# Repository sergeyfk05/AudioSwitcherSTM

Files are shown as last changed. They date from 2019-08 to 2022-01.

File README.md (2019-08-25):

# Description
This project receives 4 or more audio channels to the input and outputs the first active audio channel in order of priority. 
If there is at least one active channel, then the logic unit is supplied to the LED and AMP outputs, thereby including a relay 
for the sound amplifier and an LED. The number of channels, sensitivity settings, pins can be configured in the settings. 
There are also other settings in the maine. All settings are well documented. There are tinctures that allow you to take 
measurements with different frequencies, individual for each channel, and much more.</br></br>

# Harware requirements
Code is written for STM32F103C8T6. Also you can use chinees' analogue.</br></br>

# Circuit and circuit board
You can find circuit, circuit board and gerber-files(needed for to order circuit board) in /Eagle/ directory. You can order the circuit board in <a href="https://JLCPCB.com">JLCPCB.com</a>.
It is very cheap, only $ 2 for 5 pcs.

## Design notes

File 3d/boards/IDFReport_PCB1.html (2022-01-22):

Altium customize

# IDF File Translation Report

Date: | | 01.01.2022
Time: | | 19:11:18
Elapsed Time: | | 00:00:00
PCB Filename | : | D:\Projects\AudioSwitcherSTM\Altium\BLE_Holder\PCB1.PcbDoc
IDF Board Filename | : | D:\Projects\AudioSwitcherSTM\3d\boards\PCB1.brd
IDF Library Filename | : | D:\Projects\AudioSwitcherSTM\3d\boards\PCB1.pro

Errors

Back to top

Warnings

Back to top

Save Warnings

Back to top

Save Errors

Back to top

Export Warnings

Back to top

Export Errors

Back to top

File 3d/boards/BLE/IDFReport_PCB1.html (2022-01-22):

Altium customize

# IDF File Translation Report

Date: | | 01.01.2022
Time: | | 19:09:44
Elapsed Time: | | 00:00:00
PCB Filename | : | D:\Projects\AudioSwitcherSTM\Altium\BLE_Holder\PCB1.PcbDoc
IDF Board Filename | : | D:\Projects\AudioSwitcherSTM\3d\boards\BLE\PCB1.brd
IDF Library Filename | : | D:\Projects\AudioSwitcherSTM\3d\boards\BLE\PCB1.pro

Errors

Back to top

Warnings

Back to top

Save Warnings

Back to top

Save Errors

Back to top

Export Warnings

Back to top

Export Errors

Back to top

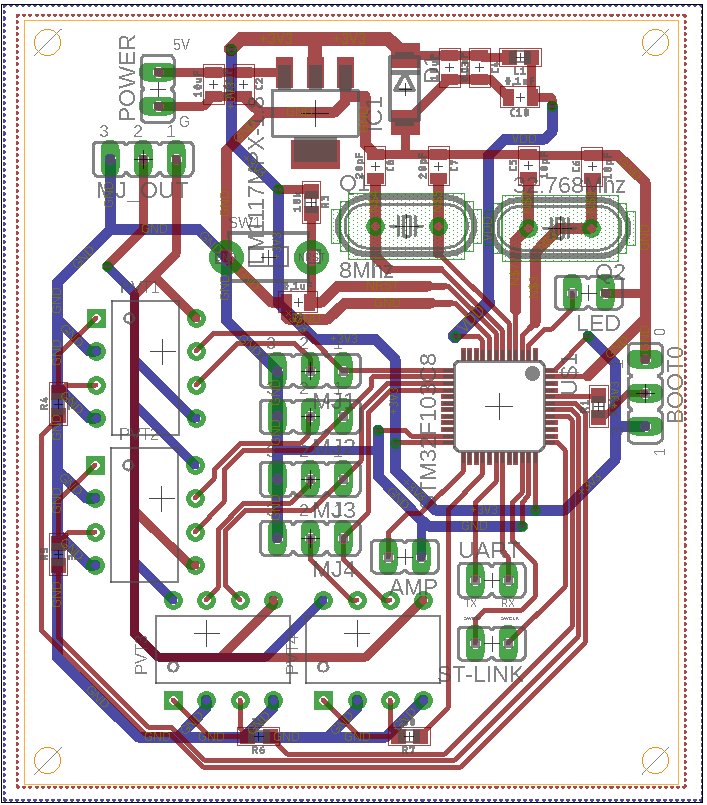
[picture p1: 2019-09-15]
scheme.png

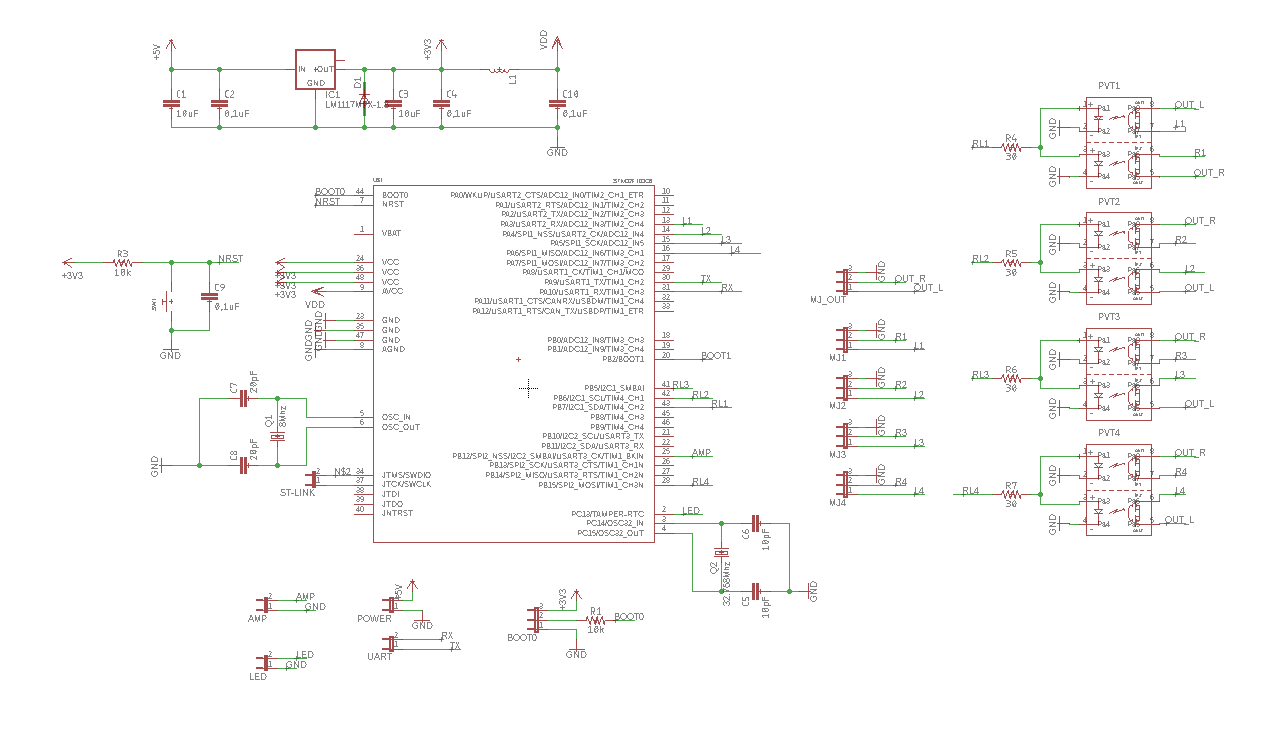
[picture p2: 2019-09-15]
circuit board.png

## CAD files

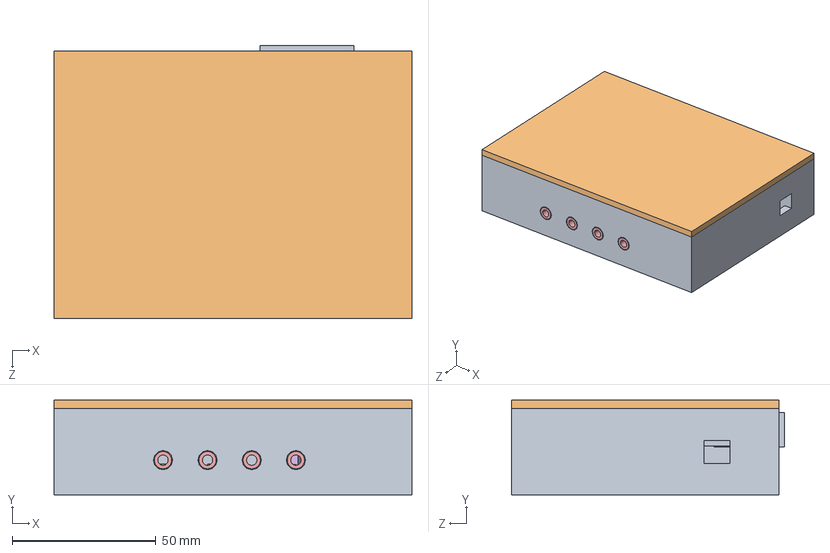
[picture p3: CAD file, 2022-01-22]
3d/case/assembly.SLDASM
124.5 x 33.0 x 95.1 mm
base_of_case
G5Q.step
Extruded.step x 10
Extruded-0.step x 5
Extruded-1.step x 30
Extruded-2.step x 15
Extruded-3.step x 8
Extruded-4.step x 16
Extruded-5.step x 5
Extruded-6.step x 10
Extruded-7.step x 2
PJ-307C.step x 5
`1.step
1.step
STM_Logo.step
TAS5-12-WEDT1.step
Extruded-8.step
Extruded-9.step
Extruded-10.step
Extruded-11.step
PCHSN-15 x 3
PCB1
771wx201
out_220v
top_of_case

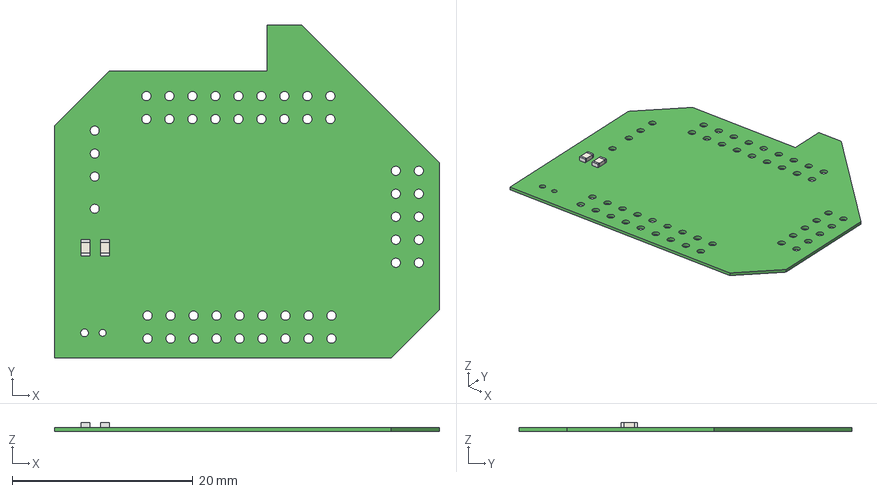
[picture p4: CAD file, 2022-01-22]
3d/boards/BLE/PCB1.step
42.5 x 36.8 x 0.961 mm
Extruded x 6

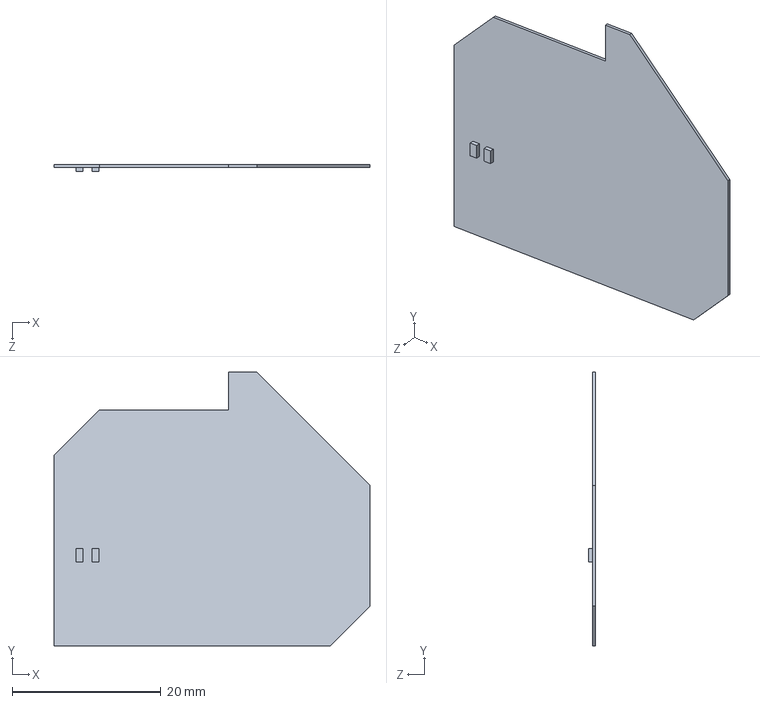
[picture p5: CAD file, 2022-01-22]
3d/boards/PCB1.SLDPRT
42.5 x 36.8 x 0.941 mm

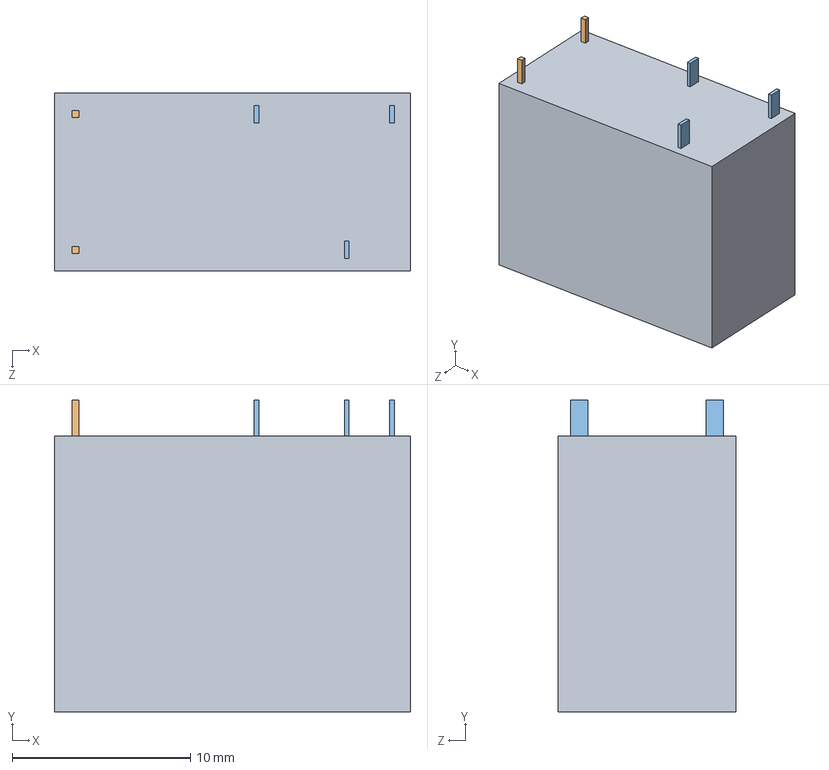
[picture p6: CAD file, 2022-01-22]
3d/components/G5Q.STEP
20.0 x 17.5 x 10.0 mm

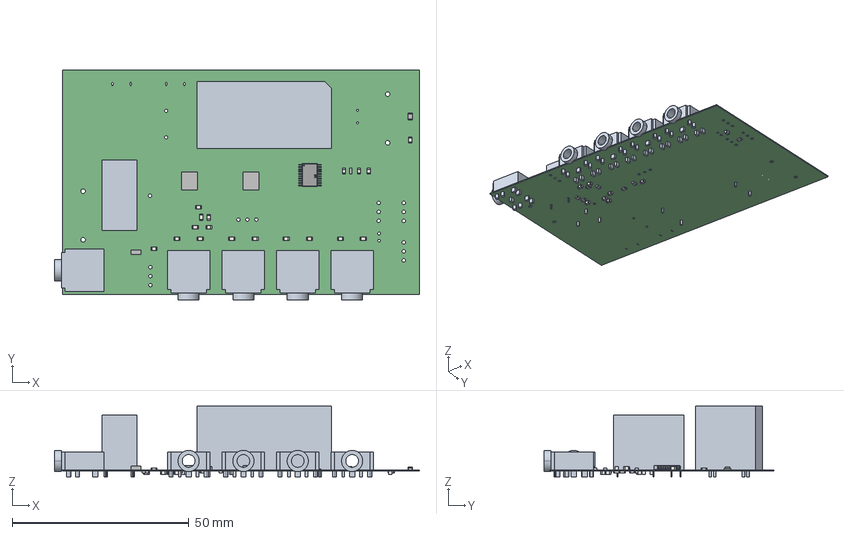
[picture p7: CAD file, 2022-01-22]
3d/boards/PCB.step
103.2 x 65.1 x 20.0 mm
G5Q
Extruded x 105
PJ-307C x 5
`1
STM_Logo
TAS5-12-WEDT1

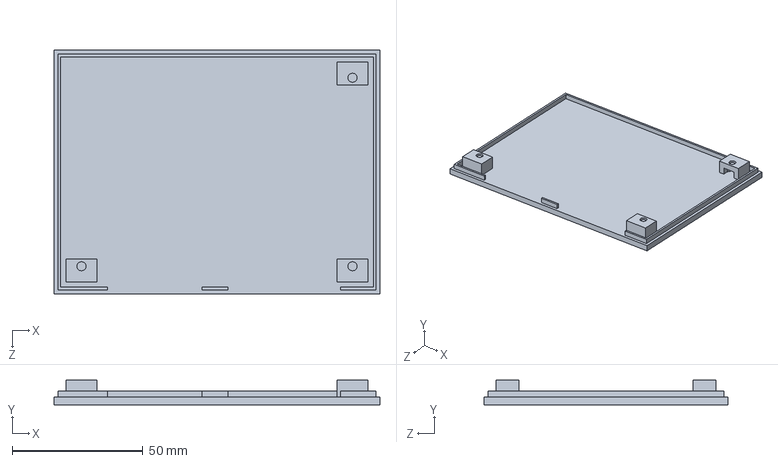
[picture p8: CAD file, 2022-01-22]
3d/case/top_of_case.SLDPRT
124.5 x 9.50 x 93.0 mm

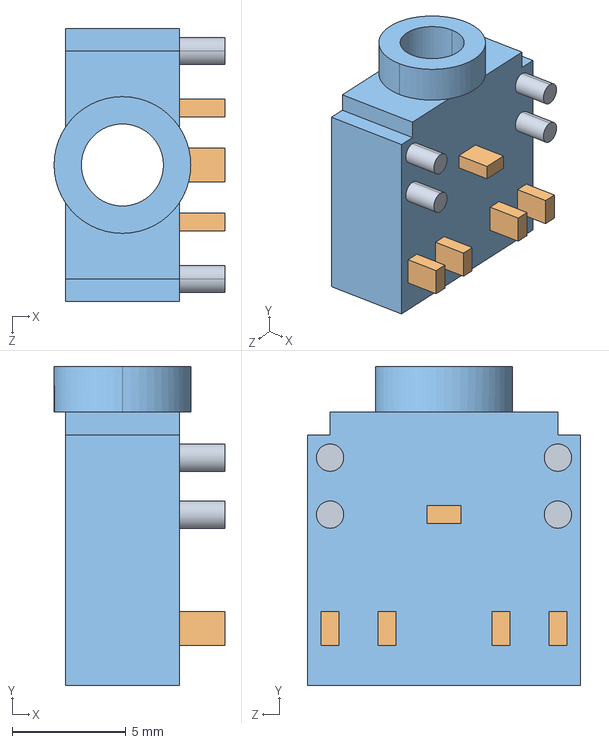
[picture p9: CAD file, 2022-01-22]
3d/components/PJ-307C.STEP
7.50 x 14.0 x 12.0 mm

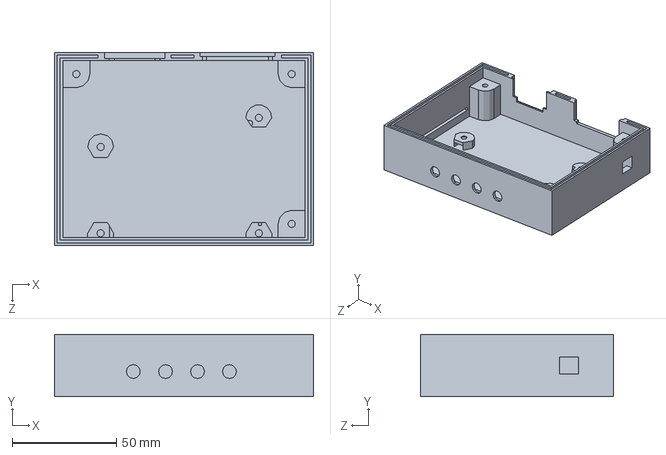
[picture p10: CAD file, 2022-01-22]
3d/case/base_of_case.SLDPRT
124.5 x 30.0 x 93.0 mm

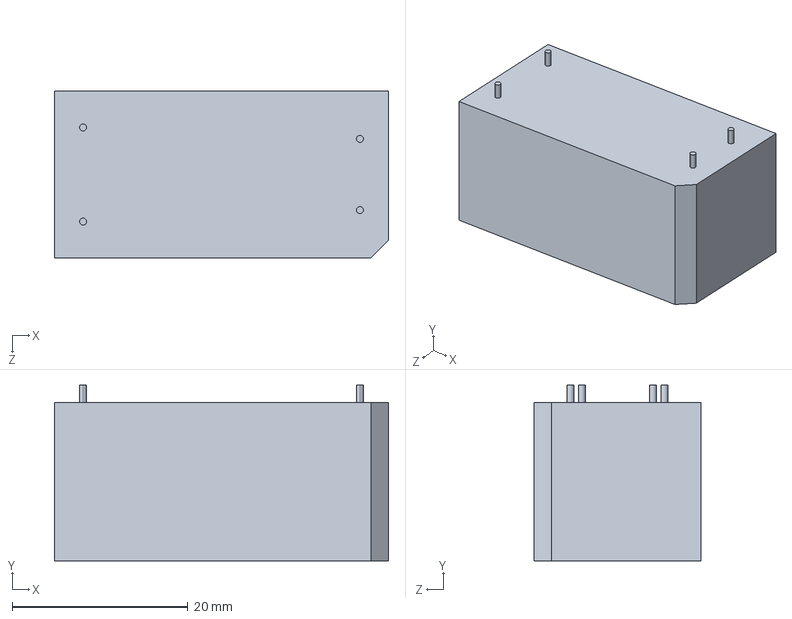
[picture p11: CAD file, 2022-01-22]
3d/components/TAS5-12-WEDT.STEP
38.0 x 20.0 x 19.0 mm

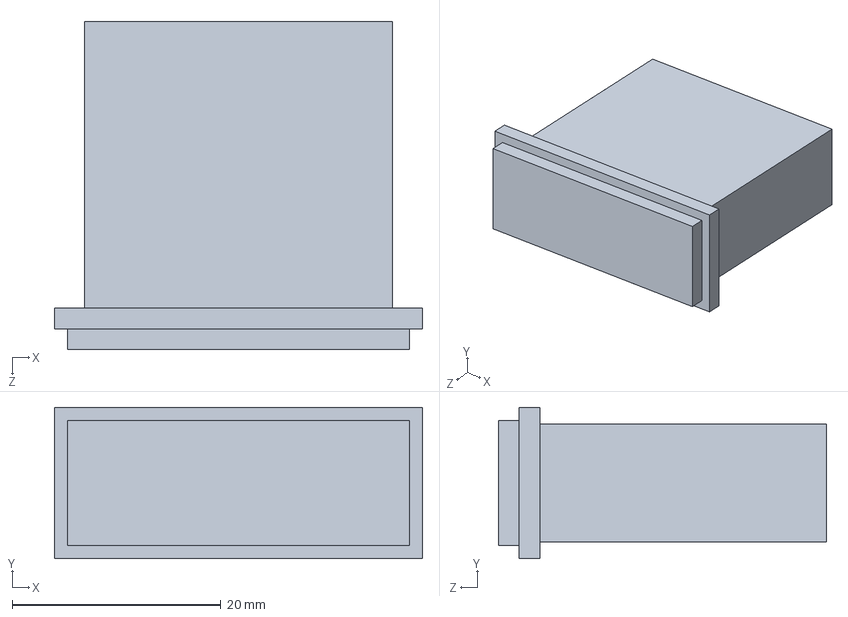
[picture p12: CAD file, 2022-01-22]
3d/case/out_220v.SLDPRT
35.3 x 14.5 x 31.5 mm

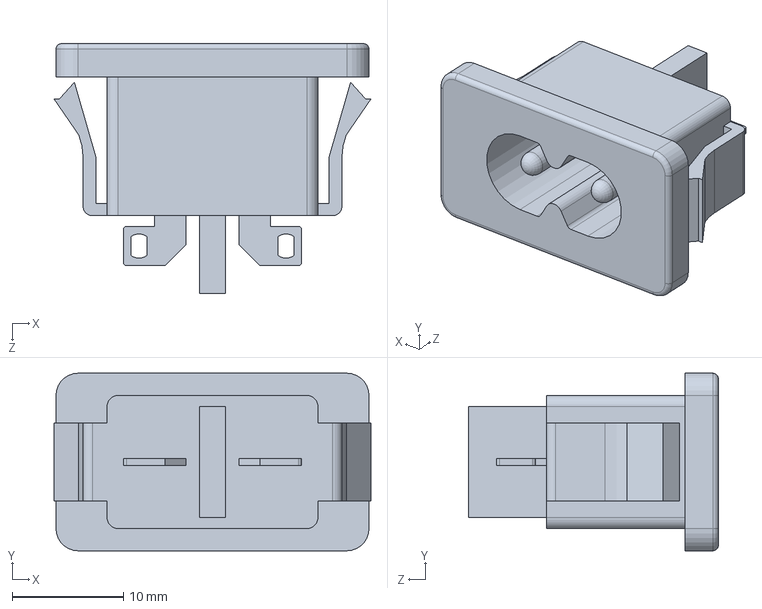
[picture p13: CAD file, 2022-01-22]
3d/case/771wx201.SLDPRT
28.6 x 16.0 x 22.5 mm

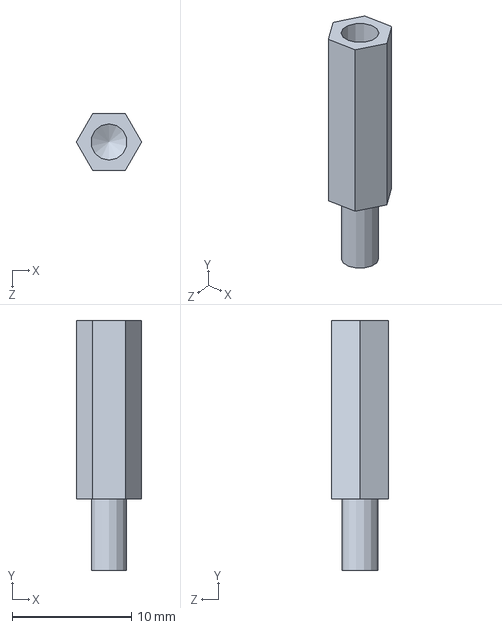
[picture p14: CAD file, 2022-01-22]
3d/case/PCHSN-15.SLDPRT
5.50 x 21.0 x 4.76 mm

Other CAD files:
3d/components/TAS5-12-WEDT1.STEP
3d/boards/BLE/PCB1.x_t
3d/components/G5Q.SLDPRT
3d/components/PJ-307C.SLDPRT
3d/components/TAS5-12-WEDT.SLDPRT

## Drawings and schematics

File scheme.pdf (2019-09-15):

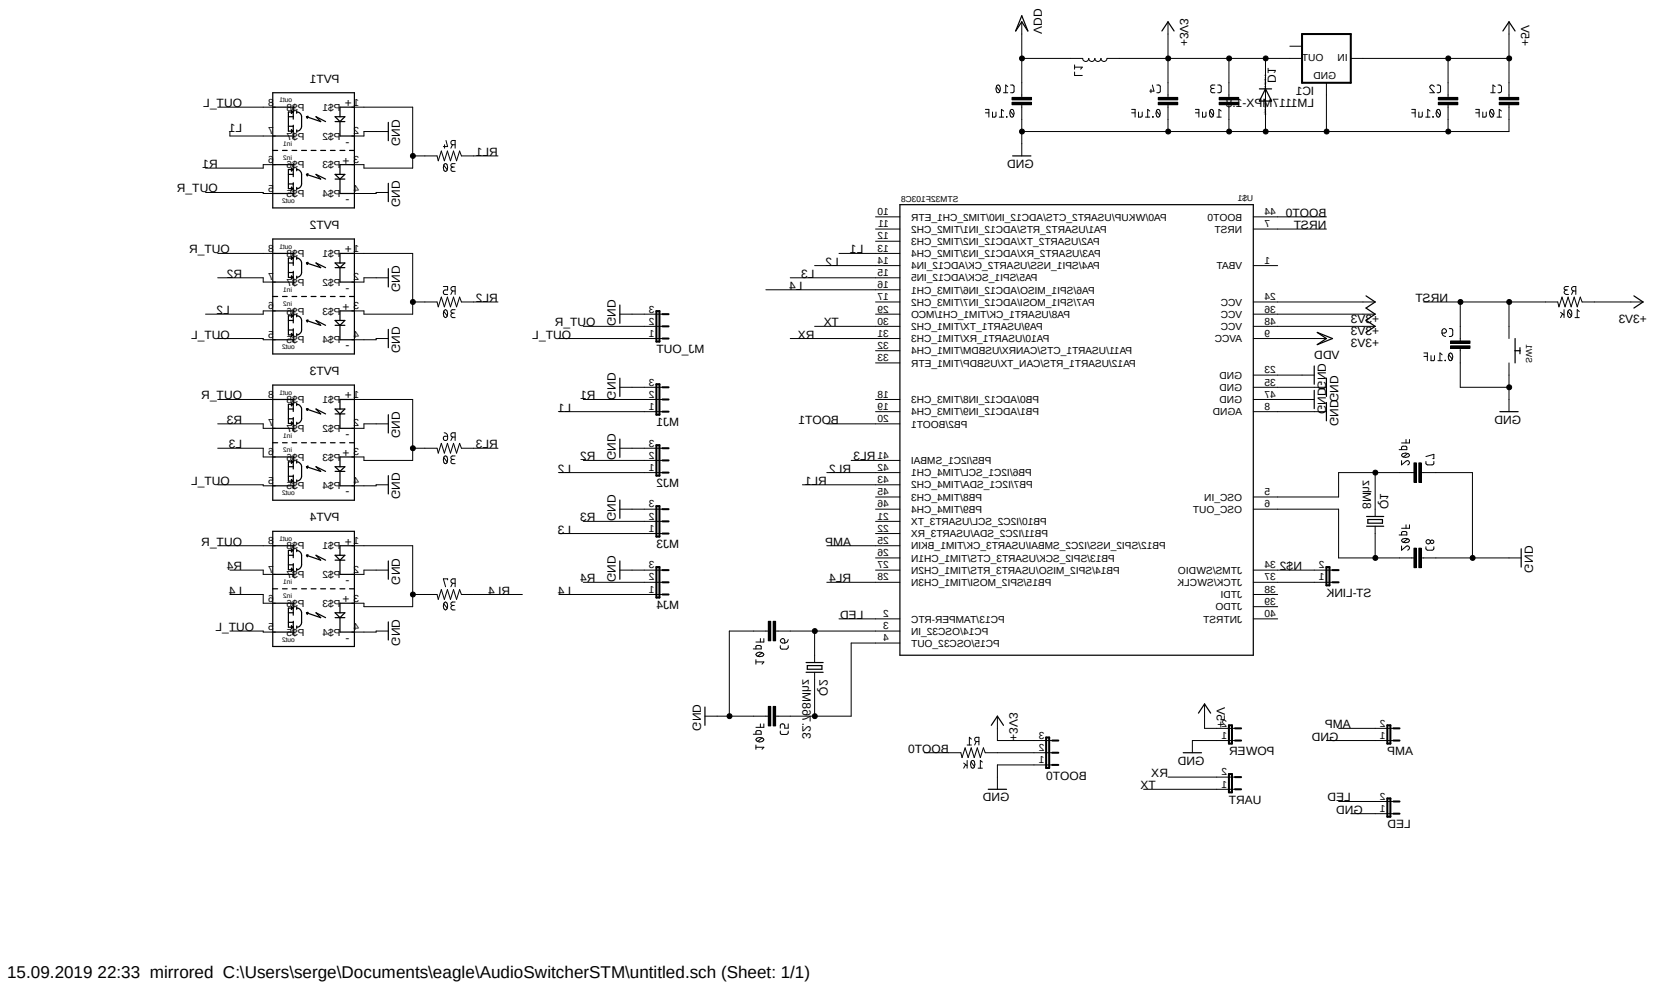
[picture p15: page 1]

GND GND GND GND GND GND GND GND GND GND GND GND GND GND +3V3 +5V

NRST 7 AGND 8 AVCC 9 PA0/WKUP/USART2_CTS/ADC12_IN0/TIM2_CH1_ETR 10 PA1/USART2_RTS/ADC12_IN1/TIM2_CH2 11 PA2/USART2_TX/ADC12_IN2/TIM2_CH3 12 PA3/USART2_RX/ADC12_IN3/TIM2_CH4 13 PA4/SPI1_NSS/USART2_CK/ADC12_IN4 14 PA5/SPI1_SCK/ADC12_IN5 15 PA6/SPI1_MISO/ADC12_IN6/TIM3_CH1 16 PA7/SPI1_MOSI/ADC12_IN7/TIM3_CH2 17 PB0/ADC12_IN8/TIM3_CH3 18 PB1/ADC12_IN9/TIM3_CH4 19 PB2/BOOT1 20 PB10/I2C2_SCL/USART3_TX 21 PB11/I2C2_SDA/USART3_RX 22 GND 23 VCC 24 PB12/SPI2_NSS/I2C2_SMBAI/USART3_CK/TIM1_BKIN 25 PB13/SPI2_SCK/USART3_CTS/TIM1_CH1N 26 PB14/SPI2_MISO/USART3_RTS/TIM1_CH2N 27 PB15/SPI2_MOSI/TIM1_CH3N 28

PA8/USART1_CK/TIM1_CH1/MCO 29 PA9/USART1_TX/TIM1_CH2 30 PA10/USART1_RX/TIM1_CH3 31 PA11/USART1_CTS/CANRX/USBDM/TIM1_CH4 32 PA12/USART1_RTS/CAN_TX/USBDP/TIM1_ETR 33

JTMS/SWDIO 34 GND 35 VCC 36

15.09.2019 22:33 mirrored C:\Users\serge\Documents\eagle\AudioSwitcherSTM\untitled.sch (Sheet: 1/1)

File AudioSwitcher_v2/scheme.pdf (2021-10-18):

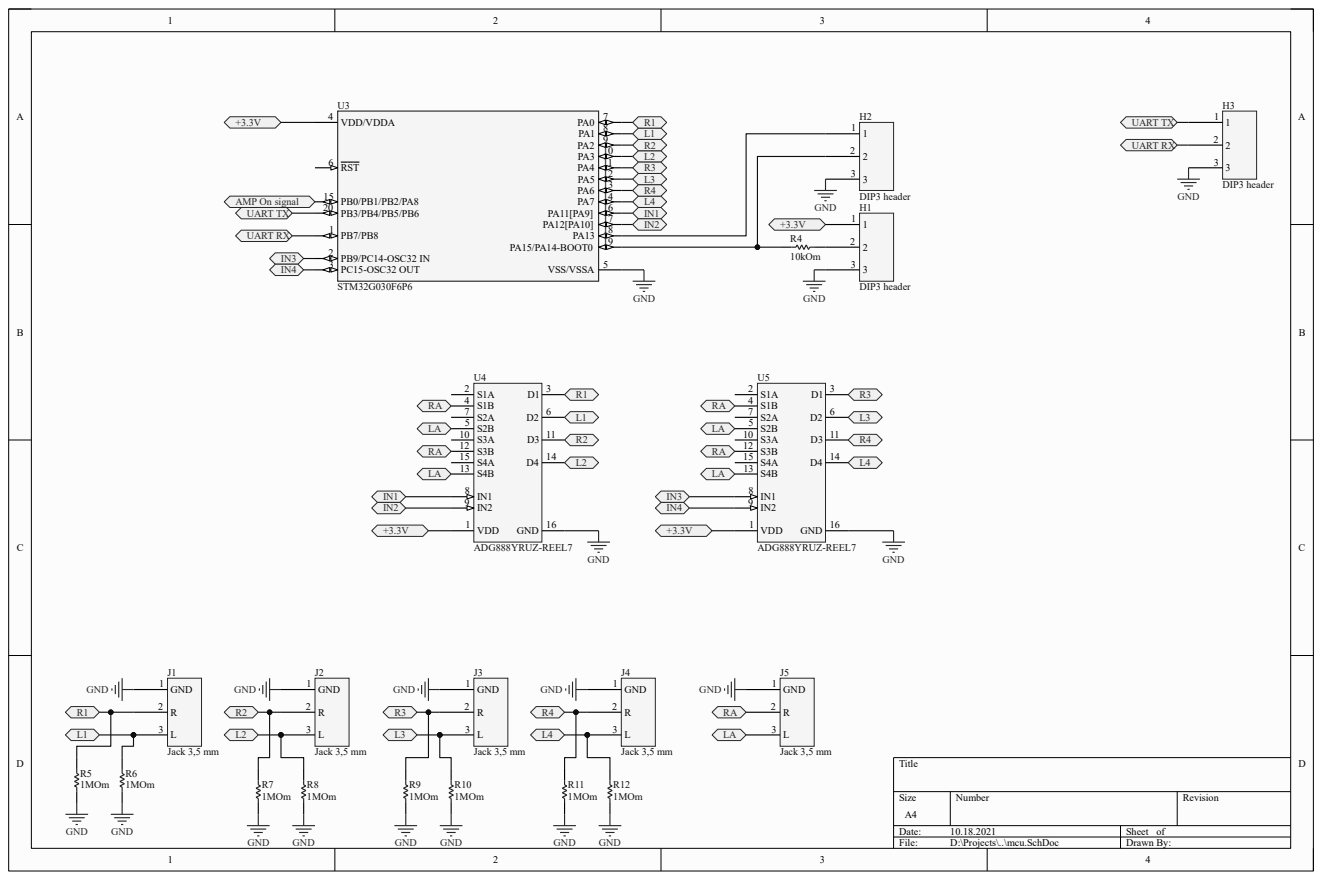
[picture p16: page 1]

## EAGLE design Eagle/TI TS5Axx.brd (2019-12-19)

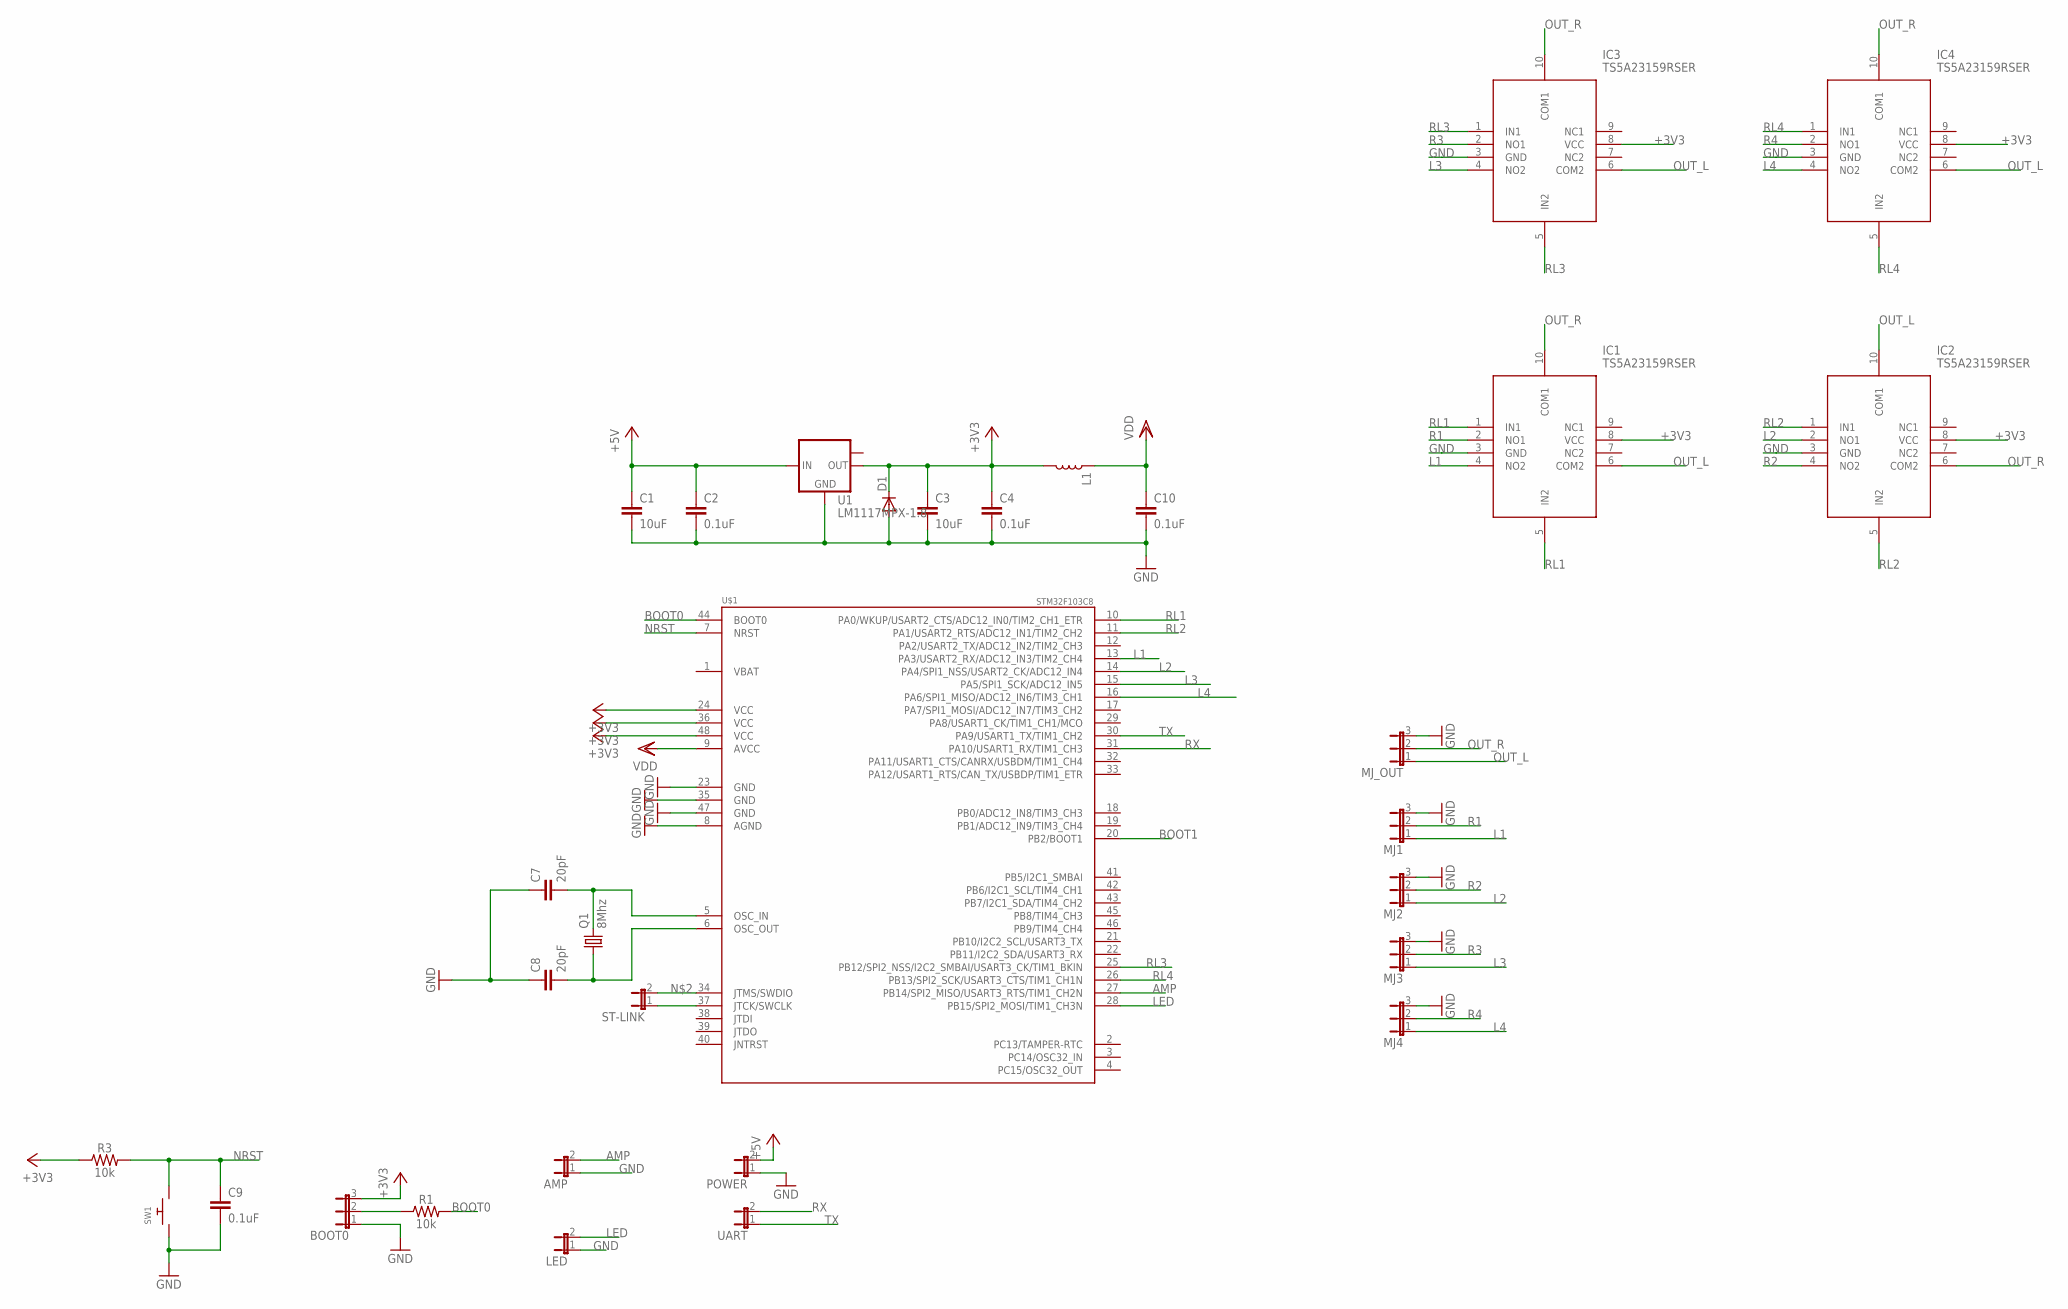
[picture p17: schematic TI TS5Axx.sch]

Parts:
AMP: JP1E; JP1
BOOT0: JP2E; JP2
C1, C3: 10uF; 0805
C2, C4, C9, C10: 0.1uF; 0805
C7, C8: 20pF; 0805
D1: DIODE-DO214AA; DO214AA
IC1, IC2, IC3, IC4: TS5A23159RSER; QFN50P150X200X60-10N
L1: INDUCTORFB-30OHM; 0603
LED: JP1E; JP1
MJ1, MJ2, MJ3, MJ4: JP2E; JP2
MJ_OUT: JP2E; JP2
POWER: JP1E; JP1
Q1: 8Mhz; HC49/S
R1, R3: 10k; 0603
ST-LINK: JP1E; JP1
SW1: SWITCH_PUSHBUTTONEVQ-PE; TACT_PANA-EVQ
U1: LM1117MPX-1.8; SOT223
U$1: STM32F103C8; LQFP48-7X7
UART: JP1E; JP1

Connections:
+3V3: BOOT0.3, C3.1, C4.1, D1.C, IC1.8 (VCC), IC2.8 (VCC), IC3.8 (VCC), IC4.8 (VCC), L1.2, R3.1, U1.2 (OUT), U$1.24 (VCC), U$1.36 (VCC), U$1.48 (VCC)
+5V: C1.1, C2.1, POWER.2, U1.3 (IN)
AMP: AMP.2, U$1.27 (PB14/SPI2_MISO/USART3_RTS/TIM1_CH2N)
BOOT0: R1.2, U$1.44 (BOOT0)
BOOT1: U$1.20 (PB2/BOOT1)
GND: AMP.1, BOOT0.1, C1.2, C2.2, C3.2, C4.2, C7.1, C8.1, C9.2, C10.2, D1.A, IC1.3 (GND), IC2.3 (GND), IC3.3 (GND), IC4.3 (GND), LED.1, MJ1.3, MJ2.3, MJ3.3, MJ4.3, MJ_OUT.3, POWER.1, SW1.P$1, U1.1 (GND), U$1.8 (AGND), U$1.23 (GND), U$1.35 (GND), U$1.47 (GND)
L1: IC1.4 (NO2), MJ1.1, U$1.13 (PA3/USART2_RX/ADC12_IN3/TIM2_CH4)
L2: IC2.2 (NO1), MJ2.1, U$1.14 (PA4/SPI1_NSS/USART2_CK/ADC12_IN4)
L3: IC3.4 (NO2), MJ3.1, U$1.15 (PA5/SPI1_SCK/ADC12_IN5)
L4: IC4.4 (NO2), MJ4.1, U$1.16 (PA6/SPI1_MISO/ADC12_IN6/TIM3_CH1)
LED: LED.2, U$1.28 (PB15/SPI2_MOSI/TIM1_CH3N)
unnamed: BOOT0.2, R1.1
unnamed: ST-LINK.2, U$1.34 (JTMS/SWDIO)
unnamed: C8.2, Q1.1, U$1.6 (OSC_OUT)
unnamed: C7.2, Q1.2, U$1.5 (OSC_IN)
unnamed: ST-LINK.1, U$1.37 (JTCK/SWCLK)
NRST: C9.1, R3.2, SW1.P$2, U$1.7 (NRST)
OUT_L: IC1.6 (COM2), IC2.10 (COM1), IC3.6 (COM2), IC4.6 (COM2), MJ_OUT.1
OUT_R: IC1.10 (COM1), IC2.6 (COM2), IC3.10 (COM1), IC4.10 (COM1), MJ_OUT.2
R1: IC1.2 (NO1), MJ1.2
R2: IC2.4 (NO2), MJ2.2
R3: IC3.2 (NO1), MJ3.2
R4: IC4.2 (NO1), MJ4.2
RL1: IC1.1 (IN1), IC1.5 (IN2), U$1.10 (PA0/WKUP/USART2_CTS/ADC12_IN0/TIM2_CH1_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)
RL2: IC2.1 (IN1), IC2.5 (IN2), U$1.11 (PA1/USART2_RTS/ADC12_IN1/TIM2_CH2)
RL3: IC3.1 (IN1), IC3.5 (IN2), U$1.25 (PB12/SPI2_NSS/I2C2_SMBAI/USART3_CK/TIM1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)
RL4: IC4.1 (IN1), IC4.5 (IN2), U$1.26 (PB13/SPI2_SCK/USART3_CTS/TIM1_CH1N)
RX: U$1.31 (PA10/USART1_RX/TIM1_CH3), UART.2
TX: U$1.30 (PA9/USART1_TX/TIM1_CH2), UART.1
VBAT: U$1.1 (VBAT)
VDD: C10.1, L1.1, U$1.9 (AVCC)

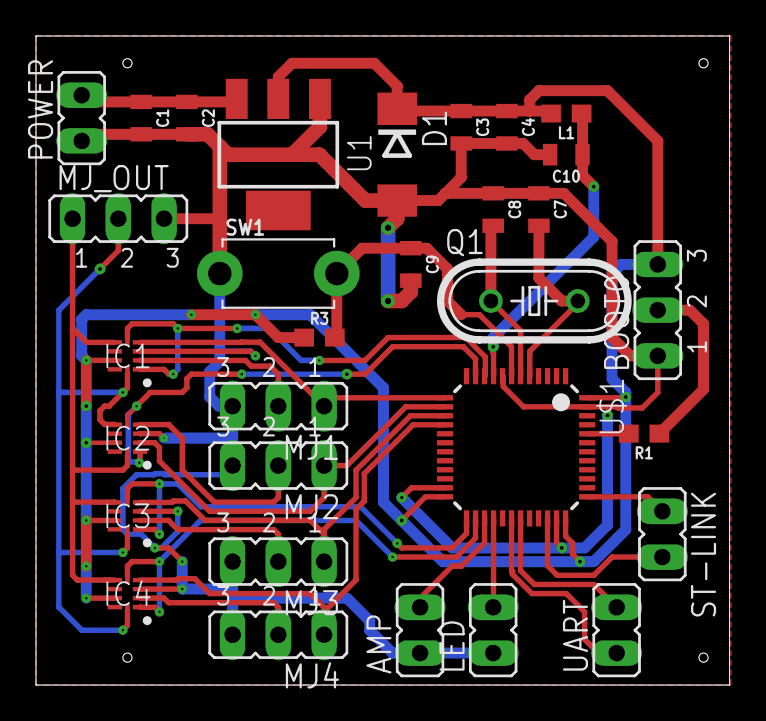
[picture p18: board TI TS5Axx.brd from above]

Board: 2 copper layers, 38.5 x 36.1 mm, 31 parts (0 on the bottom side), 29 nets.

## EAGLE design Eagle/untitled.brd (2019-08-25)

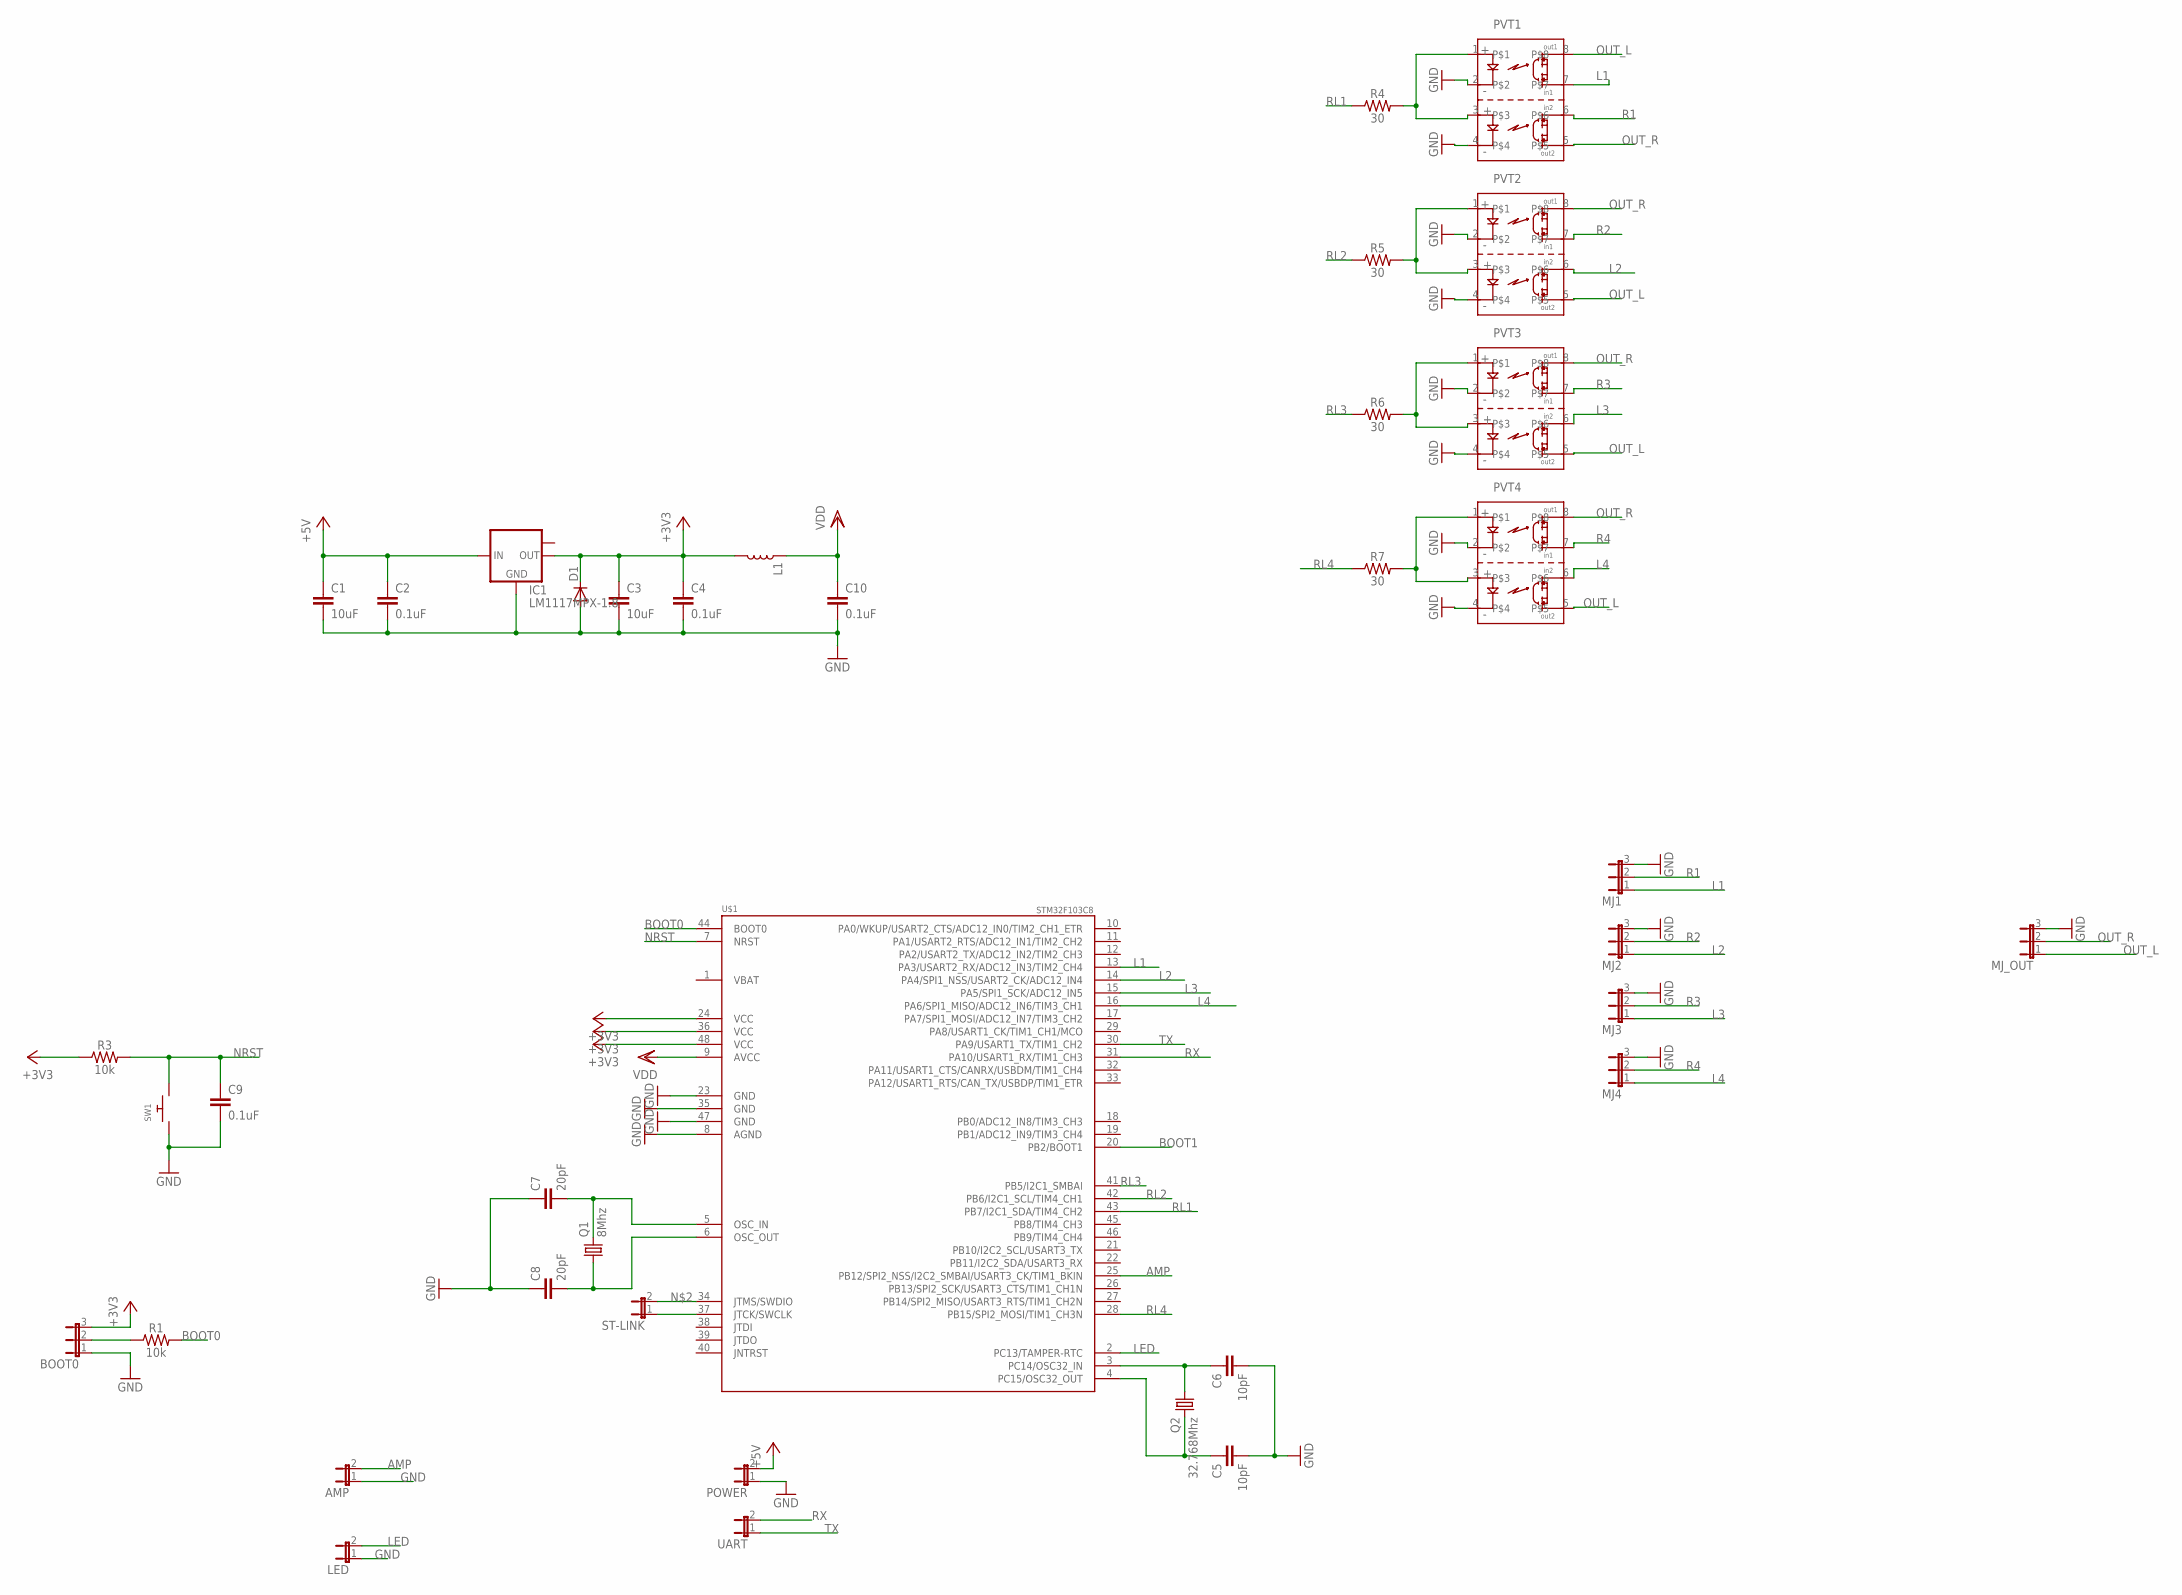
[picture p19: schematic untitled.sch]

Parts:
AMP: JP1E; JP1
BOOT0: JP2E; JP2
C1, C3: 10uF; 0805
C2, C4, C9, C10: 0.1uF; 0805
C5, C6: 10pF; 0805
C7, C8: 20pF; 0805
D1: DIODE-DO214AA; DO214AA
IC1: LM1117MPX-1.8; SOT223
L1: INDUCTORFB-30OHM; 0603
LED: JP1E; JP1
MJ1, MJ2, MJ3, MJ4: JP2E; JP2
MJ_OUT: JP2E; JP2
POWER: JP1E; JP1
PVT1, PVT2, PVT3, PVT4: PVT322A; DIP-8
Q1: 8Mhz; HC49/S
Q2: 32.768Mhz; HC49/S
R1, R3: 10k; 0603
R4, R5, R6, R7: 30; 0603
ST-LINK: JP1E; JP1
SW1: SWITCH_PUSHBUTTONEVQ-PE; TACT_PANA-EVQ
U$1: STM32F103C8; LQFP48-7X7
UART: JP1E; JP1

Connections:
+3V3: BOOT0.3, C3.1, C4.1, D1.C, IC1.2 (OUT), L1.2, R3.1, U$1.24 (VCC), U$1.36 (VCC), U$1.48 (VCC)
+5V: C1.1, C2.1, IC1.3 (IN), POWER.2
AMP: AMP.2, U$1.25 (PB12/SPI2_NSS/I2C2_SMBAI/USART3_CK/TIM1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)
BOOT0: R1.2, U$1.44 (BOOT0)
BOOT1: U$1.20 (PB2/BOOT1)
GND: AMP.1, BOOT0.1, C1.2, C2.2, C3.2, C4.2, C5.2, C6.2, C7.1, C8.1, C9.2, C10.2, D1.A, IC1.1 (GND), LED.1, MJ1.3, MJ2.3, MJ3.3, MJ4.3, MJ_OUT.3, POWER.1, PVT1.2, PVT1.4, PVT2.2, PVT2.4, PVT3.2, PVT3.4, PVT4.2, PVT4.4, SW1.P$1, U$1.8 (AGND), U$1.23 (GND), U$1.35 (GND), U$1.47 (GND)
L1: MJ1.1, PVT1.7, U$1.13 (PA3/USART2_RX/ADC12_IN3/TIM2_CH4)
L2: MJ2.1, PVT2.6, U$1.14 (PA4/SPI1_NSS/USART2_CK/ADC12_IN4)
L3: MJ3.1, PVT3.6, U$1.15 (PA5/SPI1_SCK/ADC12_IN5)
L4: MJ4.1, PVT4.6, U$1.16 (PA6/SPI1_MISO/ADC12_IN6/TIM3_CH1)
LED: LED.2, U$1.2 (PC13/TAMPER-RTC)
unnamed: BOOT0.2, R1.1
unnamed: ST-LINK.2, U$1.34 (JTMS/SWDIO)
unnamed: C6.1, Q2.1, U$1.3 (PC14/OSC32_IN)
unnamed: C8.2, Q1.1, U$1.6 (OSC_OUT)
unnamed: C7.2, Q1.2, U$1.5 (OSC_IN)
unnamed: PVT1.1, PVT1.3, R4.2
unnamed: C5.1, Q2.2, U$1.4 (PC15/OSC32_OUT)
unnamed: PVT2.1, PVT2.3, R5.2
unnamed: ST-LINK.1, U$1.37 (JTCK/SWCLK)
unnamed: PVT3.1, PVT3.3, R6.2
unnamed: PVT4.1, PVT4.3, R7.2
NRST: C9.1, R3.2, SW1.P$2, U$1.7 (NRST)
OUT_L: MJ_OUT.1, PVT1.8, PVT2.5, PVT3.5, PVT4.5
OUT_R: MJ_OUT.2, PVT1.5, PVT2.8, PVT3.8, PVT4.8
R1: MJ1.2, PVT1.6
R2: MJ2.2, PVT2.7
R3: MJ3.2, PVT3.7
R4: MJ4.2, PVT4.7
RL1: R4.1, U$1.43 (PB7/I2C1_SDA/TIM4_CH2)
RL2: R5.1, U$1.42 (PB6/I2C1_SCL/TIM4_CH1)
RL3: R6.1, U$1.41 (PB5/I2C1_SMBAI)
RL4: R7.1, U$1.28 (PB15/SPI2_MOSI/TIM1_CH3N)
RX: U$1.31 (PA10/USART1_RX/TIM1_CH3), UART.2
TX: U$1.30 (PA9/USART1_TX/TIM1_CH2), UART.1
VBAT: U$1.1 (VBAT)
VDD: C10.1, L1.1, U$1.9 (AVCC)

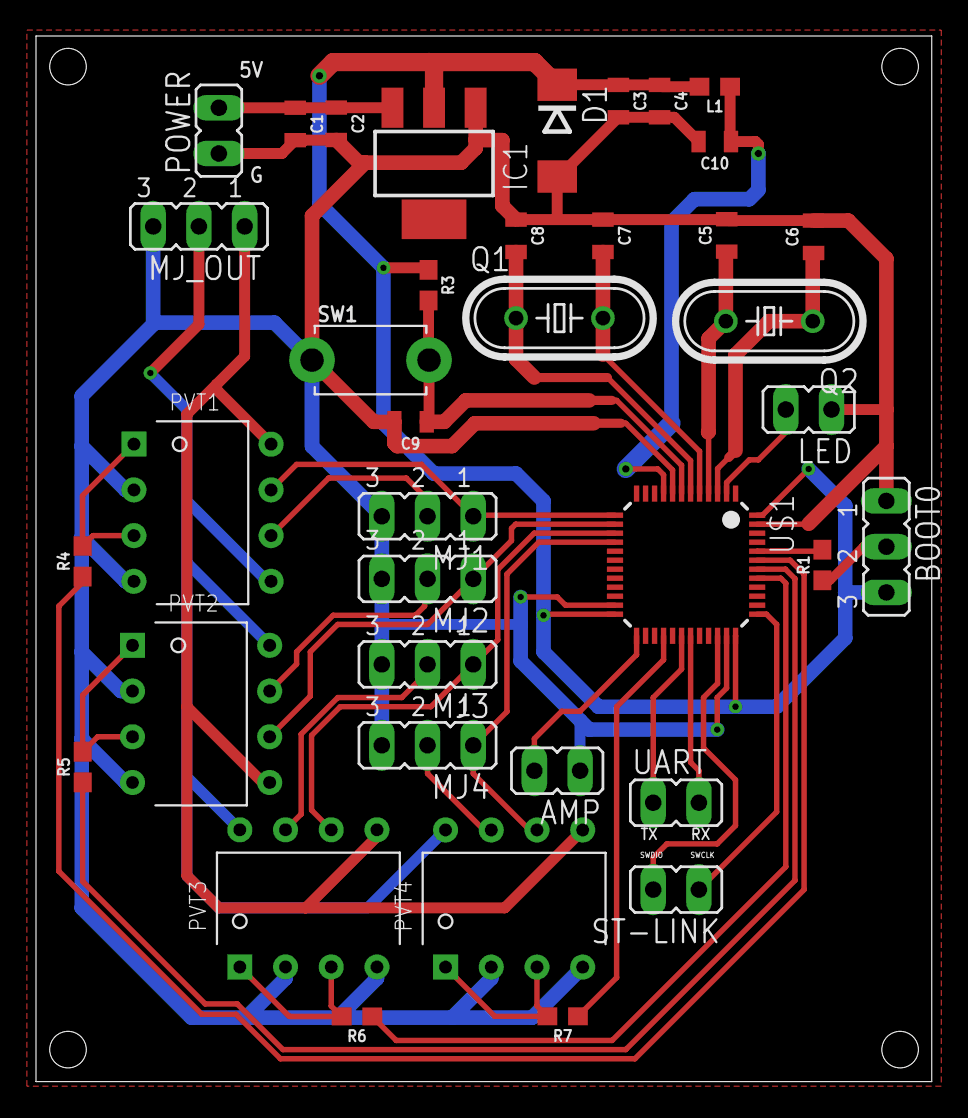
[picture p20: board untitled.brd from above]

Board: 2 copper layers, 49.8 x 58.1 mm, 38 parts (0 on the bottom side), 35 nets.

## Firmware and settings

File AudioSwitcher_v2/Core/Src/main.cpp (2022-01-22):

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
/* Includes ------------------------------------------------------------------*/
#include "main.h"
#include <IRremote.h>
#include "adc.h"
#include "dma.h"
#include "iwdg.h"
#include "gpio.h"
#include "tim.h"

/* USER CODE BEGIN Includes */
#include <stdio.h>
#include <string.h>
#include <AudioAnalyzer/Analyzer.h>
#include <AudioSwitcher/SimpleAudioSwitcher.h>
/* USER CODE END Includes */

/* USER CODE BEGIN PTD */
volatile uint16_t adc_buffer[8];
#define CHANNELS_COUNT (4)
#define AMP_ON() 		(HAL_GPIO_WritePin(GPIOB, GPIO_PIN_0, GPIO_PIN_SET))
#define AMP_OFF() 		(HAL_GPIO_WritePin(GPIOB, GPIO_PIN_0, GPIO_PIN_RESET))
/* USER CODE END PTD */

/* USER CODE BEGIN PM */
AudioSwitcher::SimpleAudioSwitcher sw1(GPIOA, GPIO_PIN_11);
AudioSwitcher::SimpleAudioSwitcher sw2(GPIOA, GPIO_PIN_12);
AudioSwitcher::SimpleAudioSwitcher sw3(GPIOB, GPIO_PIN_9);
AudioSwitcher::SimpleAudioSwitcher sw4(GPIOC, GPIO_PIN_15);

AudioAnalyzer::Analyzer analyzer1(&adc_buffer[0], &adc_buffer[1]);
AudioAnalyzer::Analyzer analyzer2(&adc_buffer[2], &adc_buffer[3]);
AudioAnalyzer::Analyzer analyzer3(&adc_buffer[4], &adc_buffer[5]);
AudioAnalyzer::Analyzer analyzer4(&adc_buffer[6], &adc_buffer[7]);

struct Channel
{
	AudioSwitcher::SimpleAudioSwitcher* switcher;
	AudioAnalyzer::Analyzer* analyzer;
};

Channel channels[CHANNELS_COUNT] = {{&sw1, &analyzer1}, {&sw2, &analyzer2}, {&sw3, &analyzer3}, {&sw4, &analyzer4}};
/* USER CODE END PM */


void SystemClock_Config(void);
/* USER CODE BEGIN 0 */
/* USER CODE BEGIN 0 */
uint8_t i = 0;
void HAL_ADC_ConvCpltCallback(ADC_HandleTypeDef* hadc)
{

	analyzer1.UpdateData();
	analyzer2.UpdateData();
	analyzer3.UpdateData();
	analyzer4.UpdateData();
}
/* USER CODE END 0 */



enum IR : uint32_t
{
	Zero = 0x97483bfb,
	One = 0xe318261b,
	Two = 0x511dbb,
	Three = 0xee886d7f,
	Four = 0x52a3d41f,
	OK = 0x488f3cbb,
};
/**
  * @brief  The application entry point.
  * @retval int
  */
extern decode_results results;
int main(void)
{
  /* MCU Configuration--------------------------------------------------------*/

  /* Reset of all peripherals, Initializes the Flash interface and the Systick. */
  HAL_Init();

  /* Configure the system clock */
  SystemClock_Config();

  /* Initialize all configured peripherals */
  MX_GPIO_Init();
  MX_DMA_Init();
  MX_ADC1_Init();
  MX_TIM3_Init();
  //MX_USART1_UART_Init();
  MX_IWDG_Init();
  /* USER CODE BEGIN 2 */

  uint32_t last_tick = HAL_GetTick();
  /* USER CODE END 2 */
HAL_GPIO_WritePin(GPIOA, GPIO_PIN_11, GPIO_PIN_RESET);
  /* Infinite loop */
  /* USER CODE BEGIN WHILE */
AMP_OFF();
/*while(1){
	sw3.SetCommutationState(true);
	HAL_IWDG_Refresh(&hiwdg);
}*/
	IR curr_mode = IR::OK;
	bool amp_state = false;
	  my_enableIRIn();
  while (1)
  {
	  HAL_IWDG_Refresh(&hiwdg);

	if(my_decode(&results))
	{
		switch(results.value)
		{
		case IR::OK:
		case IR::One:
		case IR::Two:
		case IR::Three:
		case IR::Four:
		case IR::Zero:
			curr_mode = (IR)results.value;
			break;
		}
		HAL_Delay(300);
		my_resume();
	}

    /* USER CODE END WHILE */
	  /*if(HAL_GetTick() - last_tick > 5)
	  {
		  last_tick = HAL_GetTick();
		  uint8_t ch_buf[100];
		  //(amp_state ? 200 : 10)
		  sprintf(reinterpret_cast<char*>(ch_buf), "$%u %u %u;", analyzer1.last_freq[0],  adc_buffer[2], adc_buffer[4]);
		  HAL_UART_Transmit_DMA(&huart1, ch_buf, strlen(reinterpret_cast<char*>(ch_buf)));
	  }*/


	  switch(curr_mode)
	  {
	  case IR::Zero:
	  {
		  AMP_OFF();
		  break;
	  }

	  case IR::One:
	  {
		  channels[0].switcher->SetCommutationState(true);
		  channels[1].switcher->SetCommutationState(false);
		  channels[2].switcher->SetCommutationState(false);
		  channels[3].switcher->SetCommutationState(false);
		  AMP_ON();
		  break;
	  }

	  case IR::Two:
	  {
		  channels[0].switcher->SetCommutationState(false);
		  channels[1].switcher->SetCommutationState(true);
		  channels[2].switcher->SetCommutationState(false);
		  channels[3].switcher->SetCommutationState(false);
		  AMP_ON();
		  break;
	  }

	  case IR::Three:
	  {
		  channels[0].switcher->SetCommutationState(false);
		  channels[1].switcher->SetCommutationState(false);
		  channels[2].switcher->SetCommutationState(true);
		  channels[3].switcher->SetCommutationState(false);
		  AMP_ON();
		  break;
	  }

	  case IR::Four:
	  {
		  channels[0].switcher->SetCommutationState(false);
		  channels[1].switcher->SetCommutationState(false);
		  channels[2].switcher->SetCommutationState(true);
		  channels[3].switcher->SetCommutationState(false);
		  AMP_ON();
		  break;
	  }

	  case IR::OK:
	  {
		  amp_state = false;
		  int8_t active_ch = -1;
		  for(uint8_t i = 0; i < CHANNELS_COUNT; i++)
		  {
			  if(channels[i].analyzer->IsAudio())
			  {
				  amp_state = true;
				  active_ch = i;
				  break;
			  }
		  }

		  if(amp_state)
		  {
			  for(uint8_t i = 0; i < CHANNELS_COUNT; i++)
			  {
				  channels[i].switcher->SetCommutationState(i == active_ch);
			  }

			  AMP_ON();
		  }
		  else
		  {
			  AMP_OFF();
		  }
		  break;
	  }


	  }





	  /*for(uint8_t i = 0; i < CHANNELS_COUNT; i++)
	  {
		  if(channels[i].analyzer->IsAudio())
		  {
			  for(uint8_t y = i + 1; y < CHANNELS_COUNT; y++)
			  {
				  channels[y].switcher->SetCommutationState(false);
			  }
			  channels[i].switcher->SetCommutationState(true);
			  amp_state = true;
			  break;
		  }
		  else
		  {
			  channels[i].switcher->SetCommutationState(false);
		  }
	  }

	  if(amp_state)
	  {
		  AMP_ON();
	  }
	  else
	  {
		  AMP_OFF();
	  }*/
    /* USER CODE BEGIN 3 */
  }
  /* USER CODE END 3 */
}

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


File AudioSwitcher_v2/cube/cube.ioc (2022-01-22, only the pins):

Mcu.UserName=STM32G030F6Px
PA0.Signal=ADC1_IN0
PA1.Signal=ADC1_IN1
PA2.Signal=ADC1_IN2
PA3.Signal=ADC1_IN3
PA4.Signal=ADC1_IN4
PA5.Signal=ADC1_IN5
PA6.Signal=ADC1_IN6
PA7.Signal=ADC1_IN7
PB0.Signal=GPIO_Output
PB7.Signal=GPIO_Input
PB9.Signal=GPIO_Output

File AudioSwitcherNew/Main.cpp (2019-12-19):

#include "Settings.cpp"
#include <stm32f10x.h>
#include "MyMath.h"
#include "MusicDetector.h"
#include "Channel.h"
#include "PeriphInit.h"
#include "USART.h"
#include <functional>
#include "IIndicators.h"
#include "IndicatorsProvider.h"


using namespace Models;
using namespace Init;
using namespace Periph;



void Reader(const volatile uint16_t* buffer, Channel** channels, uint8_t channelsCount);
std::function<void()> ReaderHandler;//method that starts when reading ADC values
std::function<void()> SwitcherHandler;//method that starts at the end of the measurement cycle

int main()
{
	PeriphInit::InitPLL();
	
	//periph select
	const uint32_t usingDMAPeriph = RCC_AHBPeriph_DMA1;
	DMA_Channel_TypeDef* usingDMA = DMA1_Channel1;
	const uint32_t usingADCPeriph = RCC_APB2Periph_ADC1;
	ADC_TypeDef* usingADC = ADC1;
	
	const uint8_t channelsCount = 2; //channels count
	Channel* channels[channelsCount];
	volatile uint16_t ADCBuffer[channelsCount];
	const uint8_t countOfIterationsForSwitch = 3; //count of detection needed for switch
	const uint8_t ADCChannels[] = { ADC_Channel_3, ADC_Channel_4, ADC_Channel_5, ADC_Channel_6 }; //input channels
	const uint16_t rellayPins[] = { GPIO_Pin_7, GPIO_Pin_6, ADC_Channel_5, GPIO_Pin_15 };//pins which commutation audio channel to output
	const uint8_t ADCSampleTime = ADC_SampleTime_239Cycles5;//ADC sample time, bigger - better
	//static uint16_t* MeasurementsBuffer[ChannelsCount];
	const uint16_t measurementsDuration = 2000;  // how often channels are checked for sound(in ms)
	const uint32_t measurementFrequencies[] = { 1000, 1000, 1000, 1000 }; //count of measurement in second of each channel
	
	
#if DEBUG0 == 1 || DEBUG1 == 1 || DEBUG2 == 1 
	USART::InitUSART();
#endif
	
	
	//calculate the timer frequency counting
	uint32_t lcm = 1;
	for (int i = 0; i < channelsCount; i++)
		lcm = Math::LCM(lcm, measurementFrequencies[i]);
	
	for (int i = 0; i < channelsCount; i++)
	{
		uint32_t bufferLength = measurementFrequencies[i] * measurementsDuration / 1000;
	
		channels[i] = new Channel(ADCChannels[i],
			GPIOA,
			0x0001 << ADCChannels[i], 
			ADCSampleTime,
			bufferLength,
			measurementFrequencies[i], 
			lcm / measurementFrequencies[i],
			GPIOB,
			rellayPins[i]);
	}
	
	//periph init
	PeriphInit::InitGPIO(channels, channelsCount);
	PeriphInit::ADC_DMAInit(channels, usingDMAPeriph, usingDMA, usingADCPeriph, usingADC, (uint32_t)ADCBuffer, channelsCount);
	PeriphInit::InitTimers(lcm, measurementsDuration);
	
	ReaderHandler = [=, &channels, &ADCBuffer]() {Reader(ADCBuffer, channels, channelsCount); };
	
	IIndicators* ind = new  IndicatorsProvider(LED_GPIO_PERIPH, LED_GPIO_GROUP, LED_GPIO_PIN, AMP_GPIO_PERIPH, AMP_GPIO_GROUP, AMP_GPIO_PIN);
	MusicDetector* detector = new MusicDetector(channels, countOfIterationsForSwitch, channelsCount, ind);
	SwitcherHandler = [=]() {detector->CheckAndSwitch(); };
	
	
	while (1)
	{
		
	}
}


//Read values from ADC
void Reader(const volatile uint16_t* buffer, Channel** channels, uint8_t channelsCount)
{
	static uint16_t currentPos = 0;

	uint16_t a = ADC1->DR;
#if DEBUG0 == 1
	char b[20];
	char buf[20];
	buf[0] = 0;
	strcat(buf, "$");
		
	for (int i = 0; i < channelsCount; i++)
	{
		sprintf(b, "%d", buffer[i]);	
		strcat(buf, b);
		if (i != channelsCount - 1)
			strcat(buf, " ");
	}

	strcat(buf, ";");
	USART::PutString(USART1, buf);
#endif
	
	for (int i = 0; i < channelsCount; i++)
	{
		channels[i]->WriteMeasurement(buffer[i]);
	}
}
extern "C" void TIM2_IRQHandler()
{
	
	if (TIM_GetITStatus(TIM2, TIM_IT_Update) == SET)
	{		
		if (ReaderHandler != NULL)
			ReaderHandler();
		
		TIM_ClearITPendingBit(TIM2, TIM_IT_Update);
	}
}

extern "C" void TIM3_IRQHandler()
{ 
	if (TIM_GetITStatus(TIM3, TIM_IT_Update) == SET) 
	{
		NVIC_DisableIRQ(TIM2_IRQn);
		
		if(SwitcherHandler != NULL)
			SwitcherHandler();
		
		
		TIM_ClearITPendingBit(TIM2, TIM_IT_Update);
		NVIC_EnableIRQ(TIM2_IRQn);		
		TIM_ClearITPendingBit(TIM3, TIM_IT_Update);
	}
}

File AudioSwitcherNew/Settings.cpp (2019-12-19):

#define DEBUG0 0//init USART and send all measurement values
#define DEBUG1 1//init USART and send information about recognition music or not
#define DEBUG2 0//just init USART
#define LED_GPIO_PERIPH RCC_APB2Periph_GPIOC
#define LED_GPIO_GROUP GPIOC
#define LED_GPIO_PIN GPIO_Pin_13 //set (-1) to disable led indicator;
#define AMP_GPIO_PERIPH RCC_APB2Periph_GPIOB
#define AMP_GPIO_GROUP GPIOB
#define AMP_GPIO_PIN GPIO_Pin_12 // set (-1) to disable turning amplifier;

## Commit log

2019-08-25 add curcuit and readme.md
    [copper_bottom.gbr, copper_top.gbr, drills.xln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]
2019-09-15 added circuit board and scheme pictures
2019-10-11 add scheme for Texas Instruments' analog switch
    [TI TS5Axx.brd, TI TS5Axx.sch]
2019-12-19 add alternative scheme
    [TI TS5Axx.brd]
2019-12-19 better architecture for channels switching
2021-10-17 new schematic
    [PCB.GBL, PCB.GBO, PCB.GBS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]
2021-10-25 fix schematic
    [PCB.PcbDoc, power.SchDoc]
2021-10-26 fix schematic and code
    [PCB.PcbDoc, ble.SchDoc, mcu.SchDoc]
2021-10-27 fix schematic and add ble holder
    [BLE_Holder.PrjPcb, PCB.PcbDoc, Sheet1.SchDoc]
2021-11-07 add ble board and more slient turn off
    [BLE_Holder.PrjPcb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]
2022-01-22 stable fw with IR remote and BLE
    [771wx201.SLDPRT, G5Q.SLDPRT, G5Q.STEP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]
2022-01-22 finish 3d
    [assembly.SLDASM, base_of_case.SLDPRT, top_of_case.SLDPRT]

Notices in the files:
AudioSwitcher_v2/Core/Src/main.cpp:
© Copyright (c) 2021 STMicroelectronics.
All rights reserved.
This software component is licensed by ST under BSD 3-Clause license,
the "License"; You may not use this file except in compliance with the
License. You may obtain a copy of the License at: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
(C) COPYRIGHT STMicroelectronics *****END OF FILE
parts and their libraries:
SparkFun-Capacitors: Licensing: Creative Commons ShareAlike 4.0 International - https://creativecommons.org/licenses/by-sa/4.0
